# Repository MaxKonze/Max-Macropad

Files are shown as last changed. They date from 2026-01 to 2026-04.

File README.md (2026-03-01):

# Max Macropad
I wanted to create a small Keyboard with shortcuts, so I can simplify a lot of tasks on my PC. For example it significantly simplifies Photoshop workflows by binding complex multi-key shortcuts to a single press on my Macropad.
Moreover I have always wanted to dive into electronics and this macropad was the perfect starting point for me. 

My Hackpad has 7 keys. 6 of those keys are macros oriented in a row2col matrix, while the 7th key is to change between two layers. I also used a rotary encoder with a switch to change the volume on my pc.

## Features:
- 7 Keys + a switch in the rotary encoder
- 1 rotary encoder
- 2 LEDs as status lights
- XIAO RP2040

## Challenges:
I had some difficulties routing my PCB, because I did this for the first time. After multiple iterations I was eventually satisfied with the result. Fusion went pretty smooth for me, because I already had a bit of Experience in 3D Modeling.

# The build process:
## PCB:
The PCB was designed in KiCAD. I used a matrix for the keys. For the 8th key I used the switch of the rotary encoder. My routing on the PCB is still a bit messy, but I already improved significantly, considering my first iteration of routing.

_Note: First I used the wrong LEDs (SK6812), but I changed them later on to the SK6812MINI-E_

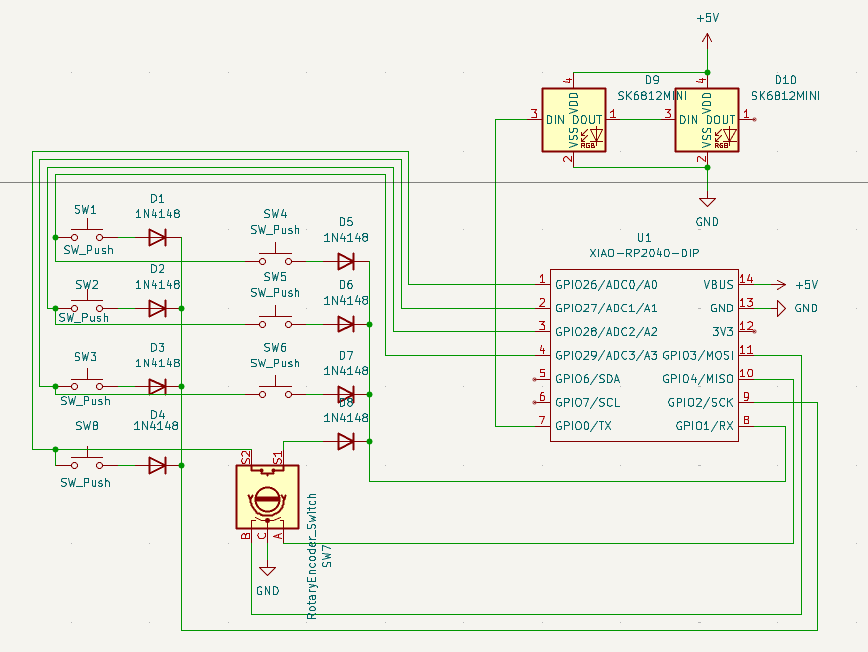
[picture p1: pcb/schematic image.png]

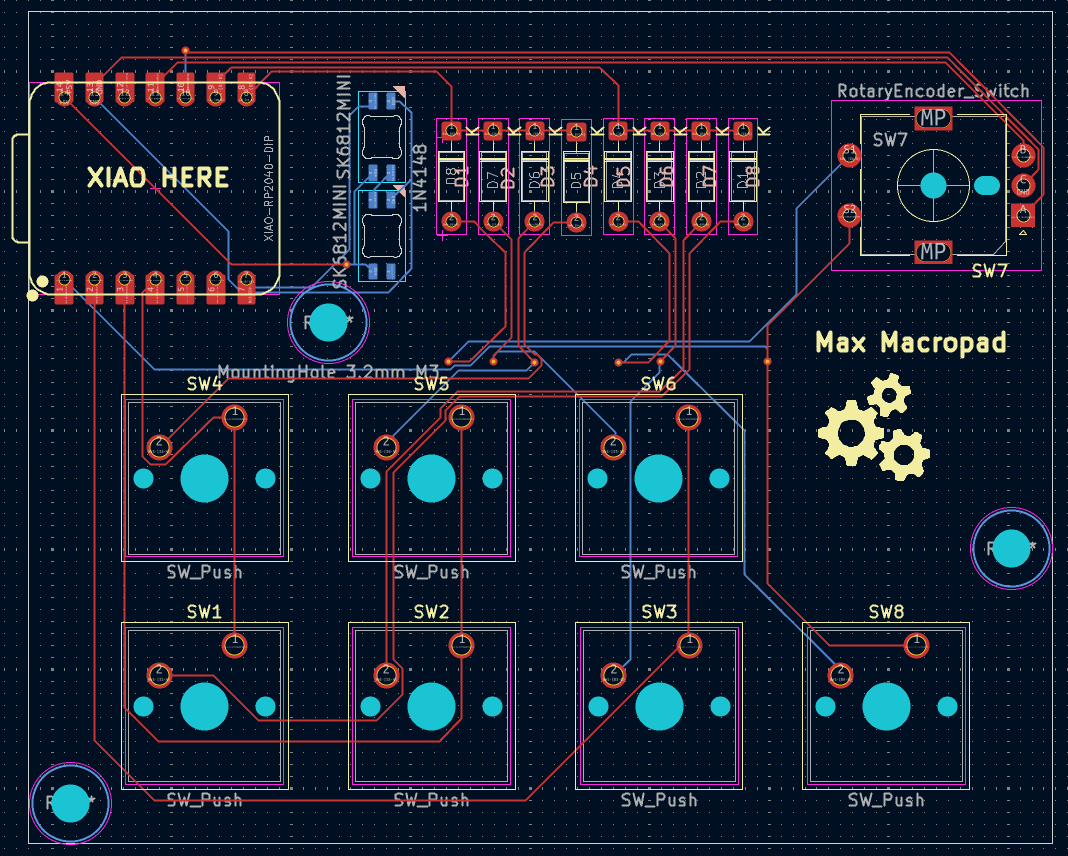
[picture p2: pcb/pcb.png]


## Case:
The case was made using Fusion. The top part of the case gets secured using M3 Screws and M3 heatset inserts. I decided to add a window to see the diodes, to give the design a bit more character. In the end I added a few design elements on the top side of my Hackpad, because I think it looks quite cool.

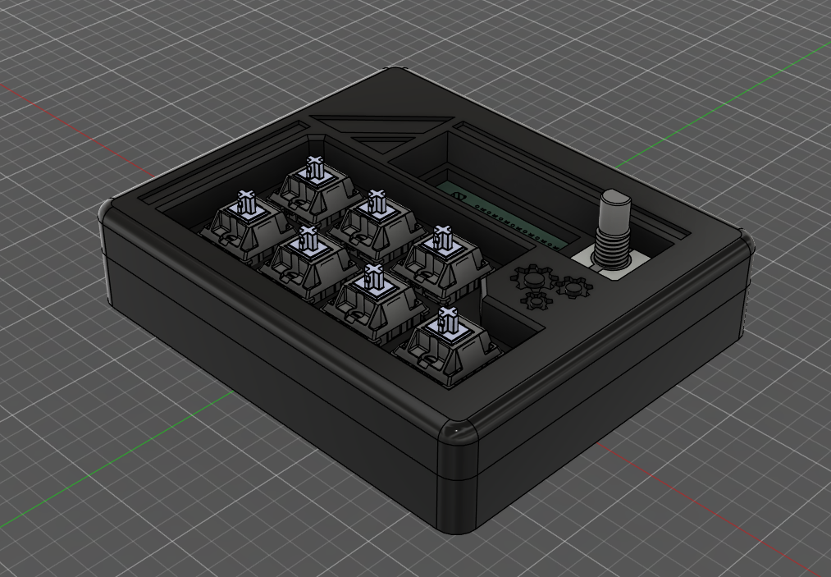
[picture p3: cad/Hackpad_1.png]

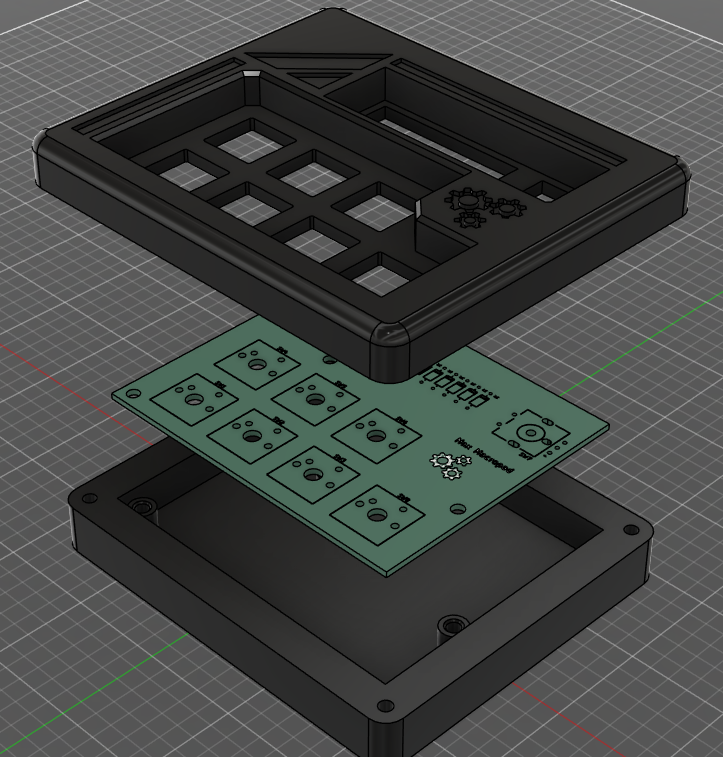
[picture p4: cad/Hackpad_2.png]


## Firmware:
I wrote the firmware using the KMK library in python. I'm using a 2-layer system to have more hotkeys on my macropad without needing more physical switches. For now I'm not 100% sure which hotkeys I want to have on my Hackpad, so I used letters as placeholders. I'll change that later. The LEDs work as a status light to show which layer is currently active.

[My Firmware](https://github.com/MaxKonze/Max-Macropad/blob/main/firmware/main.py)

# BOM:
|Amount|Part|
|---|---
| 1x |XIAO RP2040 (with pins, so I can solder it through-hole)|
| 7x |Cherry MX Switches|
| 1x |EC11 Rotary Encoder EC11 + Switch + Vertical H20mm MountingHoles & 1x Knob|
| 7x |DSA Keycaps|
| 8x |1N4148 Diodes|
| 2x |SK6812 MINI-E LEDs|
| 7x |M3 Screws|
| 7x |M3 heat inserts|
| 1x |3D Printed Case|

(I used 3 more screws and heat inserts than allowed the secure my pcb in place. If it is not possible to ship those, I will just order them by myself.)

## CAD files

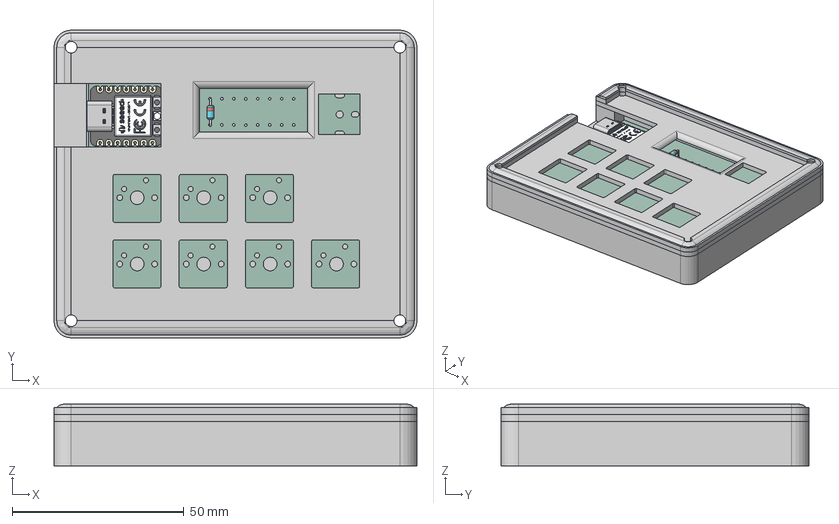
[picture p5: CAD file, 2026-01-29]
cad/Hackpad.stp
105.7 x 89.6 x 18.0 mm
type-c v2
smd_button v3
DOUT
DIN
VSS
VDD
smd_button v3(Mirror)
D_DO-35_SOD27_P7.62mm_Horizontal
Schematic_PCB
Schematic_silkscreen
top plate

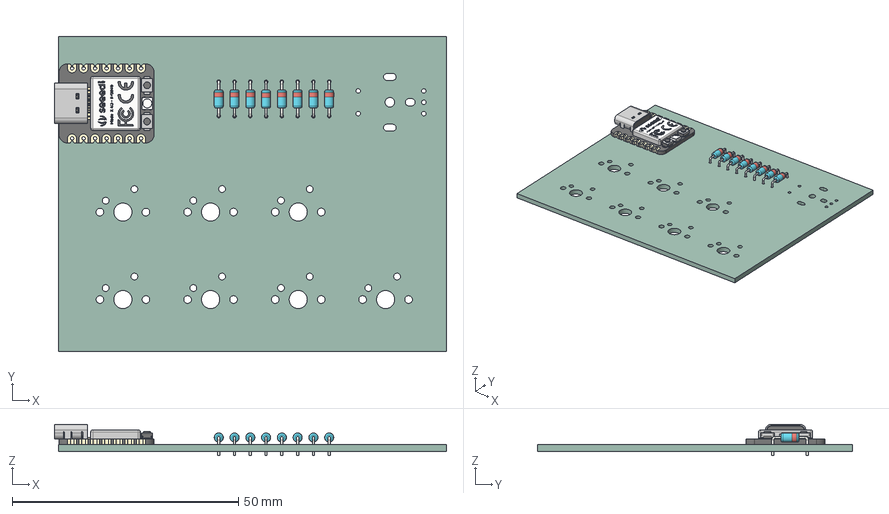
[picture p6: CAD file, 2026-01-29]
pcb/pcb.step
86.6 x 69.6 x 6.91 mm
D_DO-35_SOD27_P7.62mm_Horizontal x 8
type-c v2
smd_button v3
DOUT
DIN
VSS
VDD
smd_button v3(Mirror)
Schematic.kicad_pcb_2_PCB

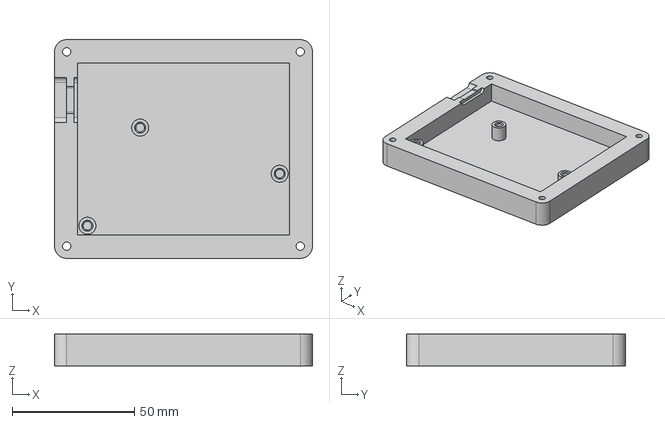
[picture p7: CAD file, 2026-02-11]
production/Bottom.stp
105.7 x 89.6 x 13.0 mm

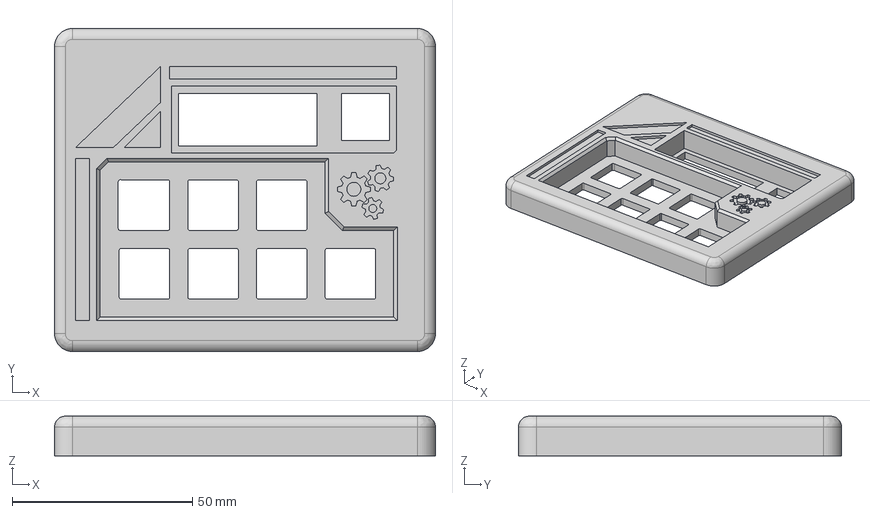
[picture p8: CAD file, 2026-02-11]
production/Top.stp
105.7 x 89.6 x 11.0 mm

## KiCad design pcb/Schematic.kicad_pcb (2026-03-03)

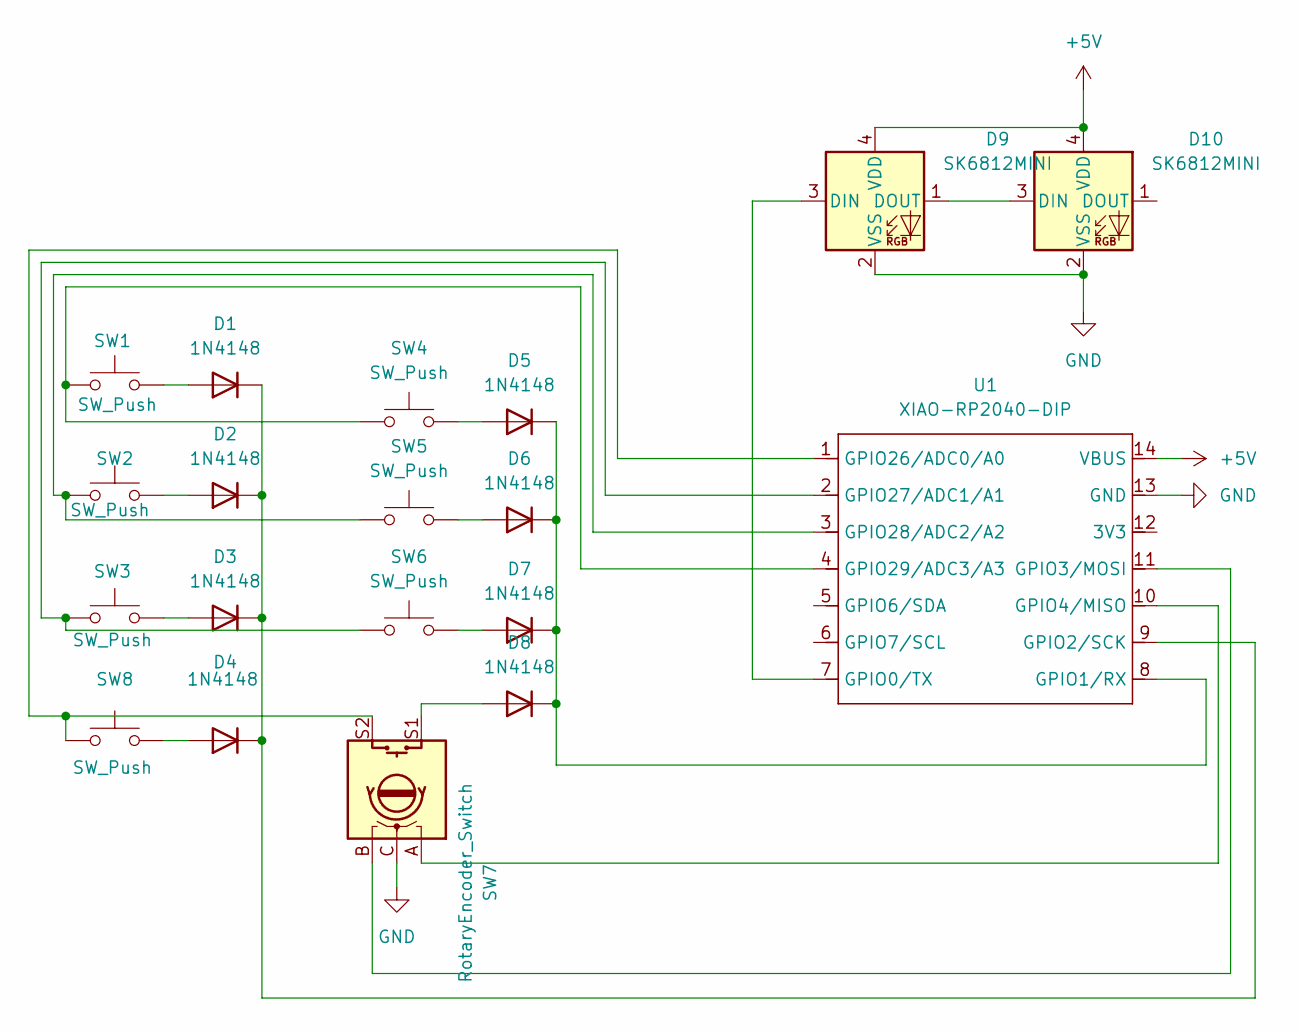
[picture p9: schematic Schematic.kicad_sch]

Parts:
D1, D2, D3, D4, D5, D6, D7, D8: 1N4148; D_DO-35_SOD27_P7.62mm_Horizontal
D9, D10: SK6812MINI; MX_SK6812MINI-E_REV
SW1, SW2, SW3, SW4, SW5, SW6, SW8: SW_Push; SW_Cherry_MX_1.00u_PCB
SW7: RotaryEncoder_Switch; RotaryEncoder_Alps_EC11E-Switch_Vertical_H20mm_MountingHoles
U1: XIAO-RP2040-DIP

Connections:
+5V: D9.4 (VDD), D10.4 (VDD), U1.14 (VBUS)
GND: D9.2 (VSS), D10.2 (VSS), SW7.C, U1.13 (GND)
unnamed: D1.2 (A), SW1.2
unnamed: D1.1 (K), D2.1 (K), D3.1 (K), D4.1 (K), U1.9 (GPIO2/SCK)
unnamed: D2.2 (A), SW2.2
unnamed: D3.2 (A), SW3.2
unnamed: D4.2 (A), SW8.2
unnamed: D5.2 (A), SW4.2
unnamed: D5.1 (K), D6.1 (K), D7.1 (K), D8.1 (K), U1.8 (GPIO1/RX)
unnamed: D6.2 (A), SW5.2
unnamed: D7.2 (A), SW6.2
unnamed: D8.2 (A), SW7.S1
unnamed: D9.3 (DIN), U1.7 (GPIO0/TX)
unnamed: D9.1 (DOUT), D10.3 (DIN)
unnamed: SW7.B, U1.11 (GPIO3/MOSI)
unnamed: SW7.A, U1.10 (GPIO4/MISO)
unnamed: SW7.S2, SW8.1, U1.1 (GPIO26/ADC0/A0)
unnamed: SW3.1, SW6.1, U1.2 (GPIO27/ADC1/A1)
unnamed: SW2.1, SW5.1, U1.3 (GPIO28/ADC2/A2)
unnamed: SW1.1, SW4.1, U1.4 (GPIO29/ADC3/A3)

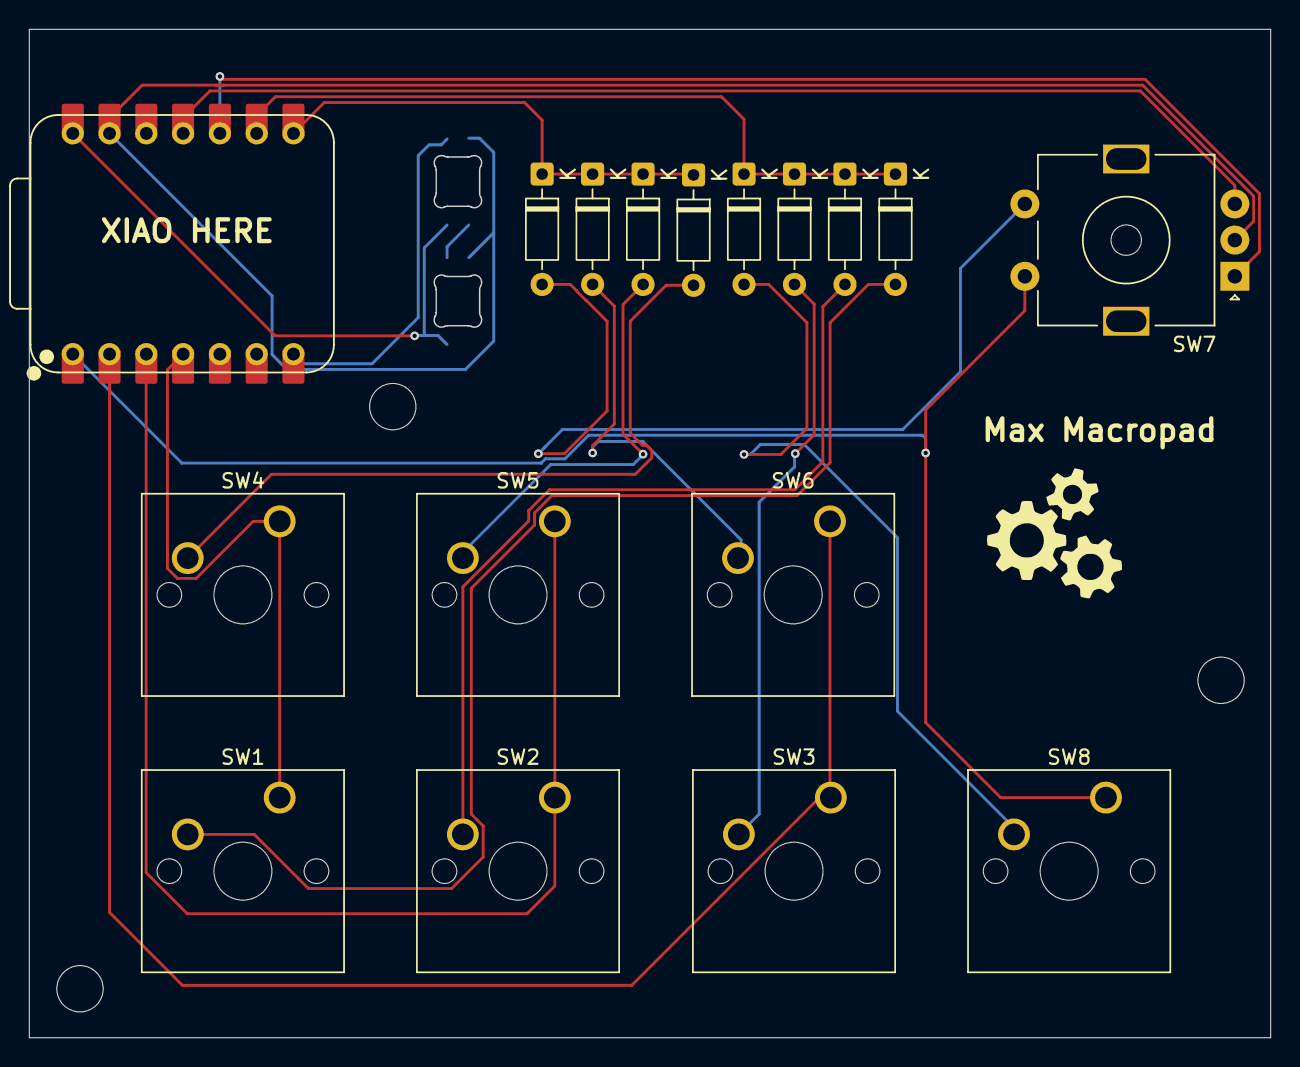
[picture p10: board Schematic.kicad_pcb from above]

Board: 2 copper layers, 85.7 x 69.6 mm, 19 parts (0 on the bottom side), 20 nets.

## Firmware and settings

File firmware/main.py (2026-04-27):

# You import all the IOs of your board
import board
import time

# These are imports from the kmk library
from kmk.kmk_keyboard import KMKKeyboard
from kmk.scanners.keypad import KeysScanner
from kmk.keys import KC
from kmk.modules.macros import Press, Release, Tap, Macros
from kmk.modules.encoder import EncoderHandler
from kmk.scanners import DiodeOrientation
from kmk.extensions.rgb import RGB
from kmk.extensions.media_keys import MediaKeys
from kmk.extensions.statusled import statusLED

# This is the main instance of your keyboard
keyboard = KMKKeyboard()

macros = Macros()
rotary_encoder = EncoderHandler()
keyboard.modules.append(macros)
keyboard.modules.append(rotary_encoder)

#rgb = RGB(pixel_pin=board.D6, num_pixels=2,val_limit=100,val_default=50,hue_default=0,sat_default=255,rgb_order=(1,0,2))
#eyboard.extensions.append(rgb)


keyboard.col_pins = (board.D7, board.D8)
keyboard.row_pins = (board.D0, board.D1, board.D2, board.D3)
keyboard.diode_orientation = DiodeOrientation.ROW2COL

keyboard.extensions.append(MediaKeys())

keyboard.keymap = [
    [
        KC.AUDIO_MUTE, KC.B,
        KC.C, KC.D,
        KC.E, KC.F,
        KC.G, KC.H,
    ]
]

rotary_encoder.pins = ((board.D9, board.D10, None, False),)  # Define pins for one rotary encoder
rotary_encoder.map = [
    ((KC.VOLU, KC.VOLD),),
]

if __name__ == '__main__':
    keyboard.go()

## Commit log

2026-01-29 init commit
    [Hackpad.stp, Schematic.kicad_pcb_2.kicad_pcb, Schematic.kicad_sch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]
2026-01-30 Revise README with additional details and corrections
    Updated the README to correct the XIAO model and added sections on challenges, build process, and BOM.
2026-01-30 Update BOM description for XIAO RP2040
    Clarified BOM item for XIAO RP2040 to specify through-hole soldering.
2026-01-30 Update BOM with specific keycap and component details
2026-02-11 new version
    [Schematic.kicad_pcb.kicad_pcb, Schematic.kicad_pcb_2.kicad_pcb]
2026-02-11 Update README with note on additional hardware
    Added note about additional screws and heat inserts used.
2026-02-11 Enhance README with case and firmware details
    Added images and improved case and firmware descriptions.
2026-02-11 prod files
    [Bottom.stp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]
2026-02-11 Adjust quantities of M3 screws and heat inserts
    Updated the quantity of M3 screws and heat inserts in the list.
2026-02-13 Revise PCB section for clarity and grammar
    Corrected grammar and improved clarity in PCB description.
2026-02-13 new gerber
    [Schematic.kicad_pcb_2-B_Cu.gbr, Schematic.kicad_pcb_2-B_Mask.gbr, Schematic.kicad_pcb_2-B_Paste.gbr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]
2026-02-20 new gerbers
    [Schematic.kicad_pcb_2-B_Cu.gbl, Schematic.kicad_pcb_2-B_Mask.gbs, Schematic.kicad_pcb_2-B_Paste.gbp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]
2026-02-20 rm gerbers
    [Schematic.kicad_pcb_2-B_Cu.gbl, Schematic.kicad_pcb_2-B_Mask.gbs, Schematic.kicad_pcb_2-B_Paste.gbp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]
2026-02-27 Enhance README with project details and BOM table
    Expanded the description of the Max Macropad project and formatted the BOM section into a table for better readability.
2026-02-28 new leds
    [Schematic.kicad_pcb.kicad_pcb, Schematic.kicad_sch]
2026-03-01 Correct status lights description and add LED note
    Updated README to reflect changes in status lights and added a note about LED revisions.
2026-03-03 new pcb (clean up)
    [Schematic.kicad_pcb.kicad_pcb]
2026-03-03 new gerbers (pcb clean up)
2026-03-03 file rename
    [Schematic.kicad_pcb]
